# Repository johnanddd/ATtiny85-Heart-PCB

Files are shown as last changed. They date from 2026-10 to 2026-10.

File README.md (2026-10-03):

# ATtiny85 Heart PCB

A custom heart-shaped PCB built around an ATtiny85 microcontroller with 24 red LEDs, four transistor-switched lighting groups, a pushbutton for changing animation modes, and non-blocking embedded firmware.

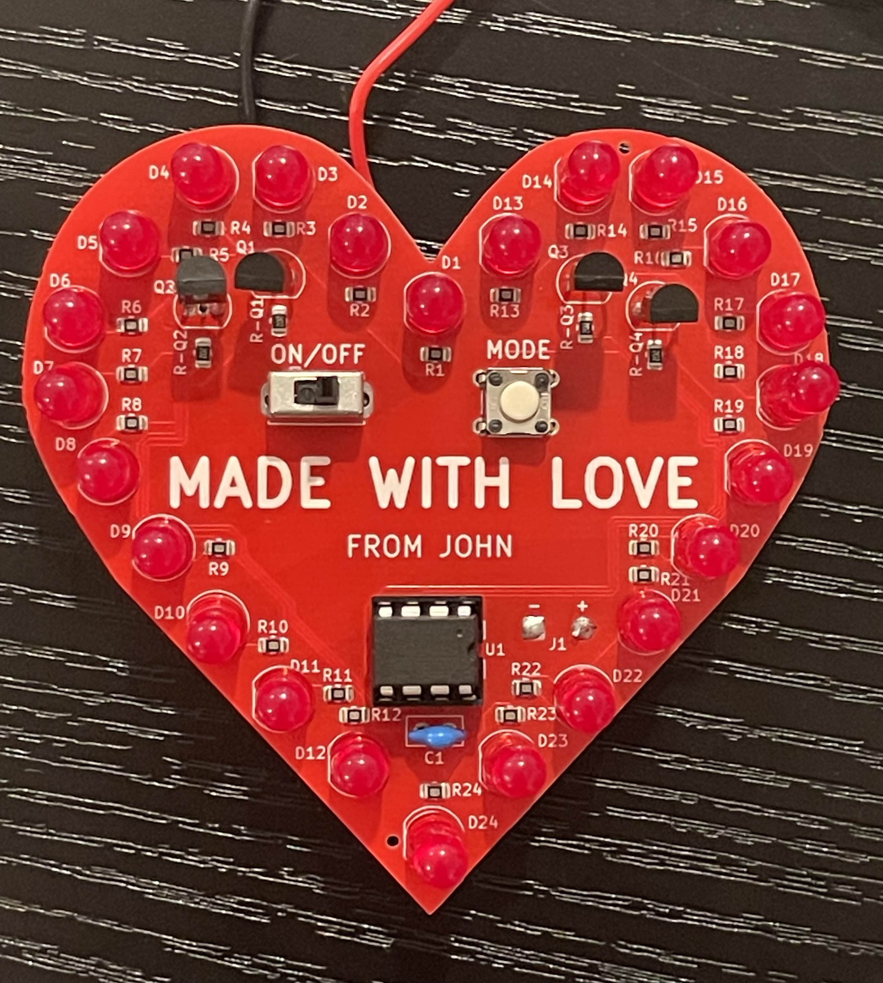
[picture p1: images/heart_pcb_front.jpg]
Finished ATtiny85 Heart PCB


## Demo

[Watch the LED animation demo on YouTube](https://youtube.com/shorts/_cduVnqTBQo)

The MODE button cycles through five lighting patterns:

1. All LEDs continuously on
2. Slow heartbeat — 500 ms on / 500 ms off
3. Fast heartbeat — 250 ms on / 250 ms off
4. Circular group sequence — Q1 → Q2 → Q4 → Q3
5. Alternating opposite groups — Q1 + Q4 ↔ Q2 + Q3

## Hardware

- ATtiny85 microcontroller
- 24 × 5 mm red LEDs
- 24 × 1 kΩ LED current-limiting resistors
- 4 × PN2222A NPN transistors
- 4 × 2 kΩ transistor base resistors
- MODE pushbutton
- ON/OFF slide switch
- 100 nF decoupling capacitor
- 3 × AA battery supply
- Custom 2-layer heart-shaped PCB

The 24 LEDs are split into four groups. Each group is switched by an NPN transistor controlled by one ATtiny85 GPIO pin.

## Schematic

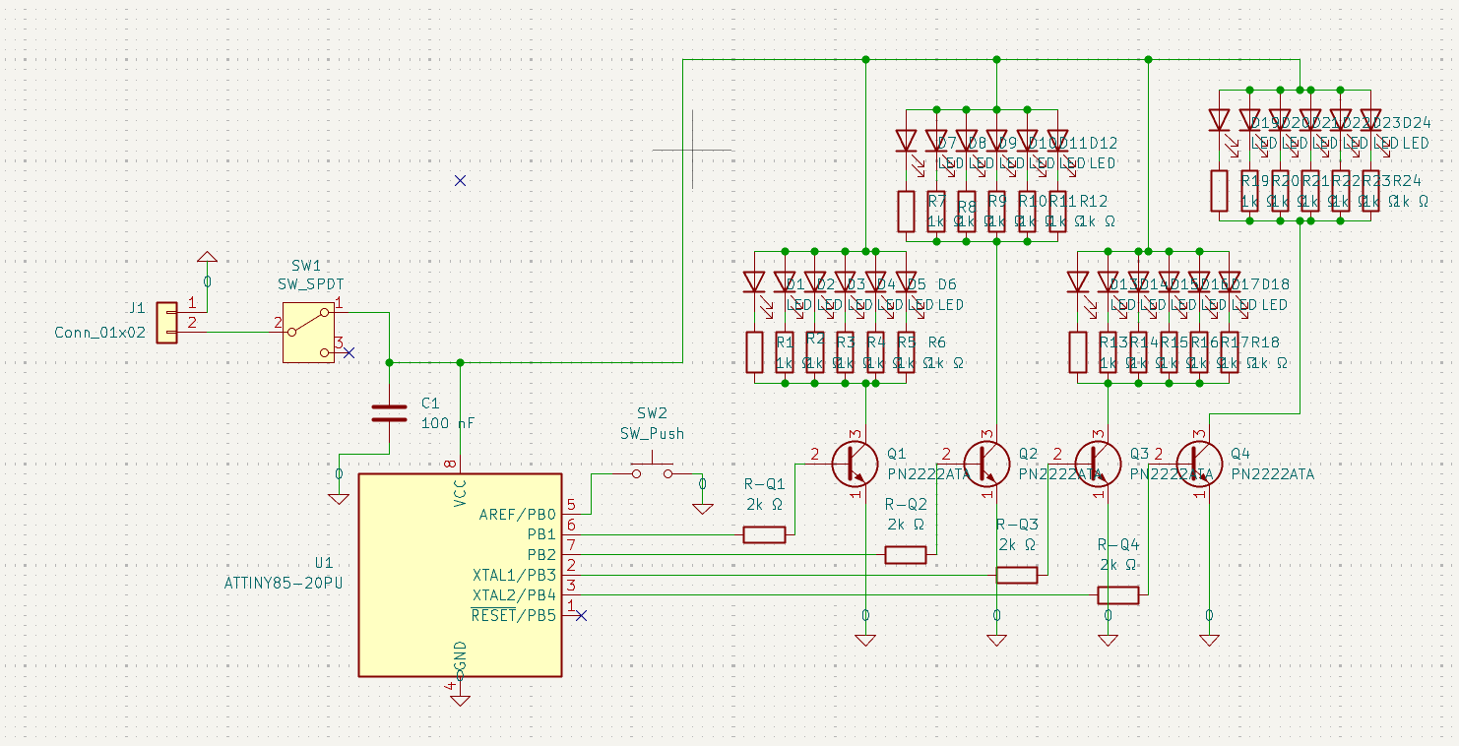
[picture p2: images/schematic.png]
Schematic


PB0 is connected to the MODE button using the ATtiny85's internal pull-up resistor. PB1–PB4 control the four transistor-switched LED groups.

## PCB Design

The board was designed in KiCad as a custom 2-layer heart-shaped PCB with a red solder mask and white silkscreen.

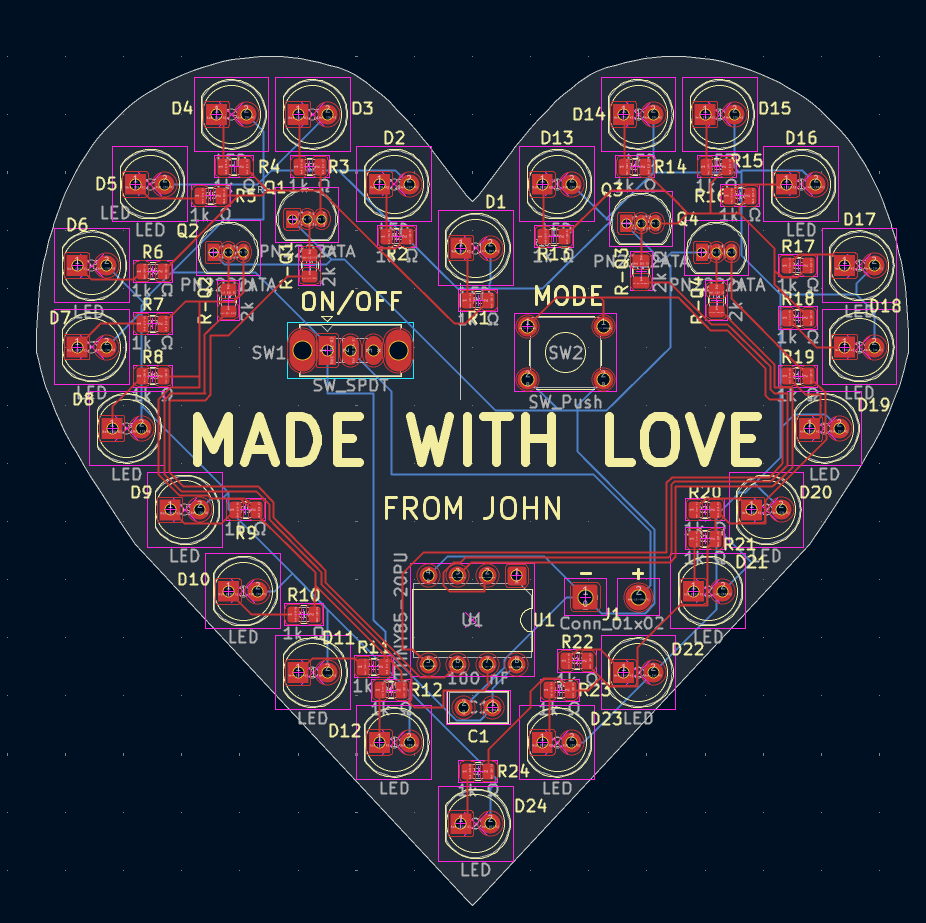
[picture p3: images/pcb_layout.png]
PCB Layout


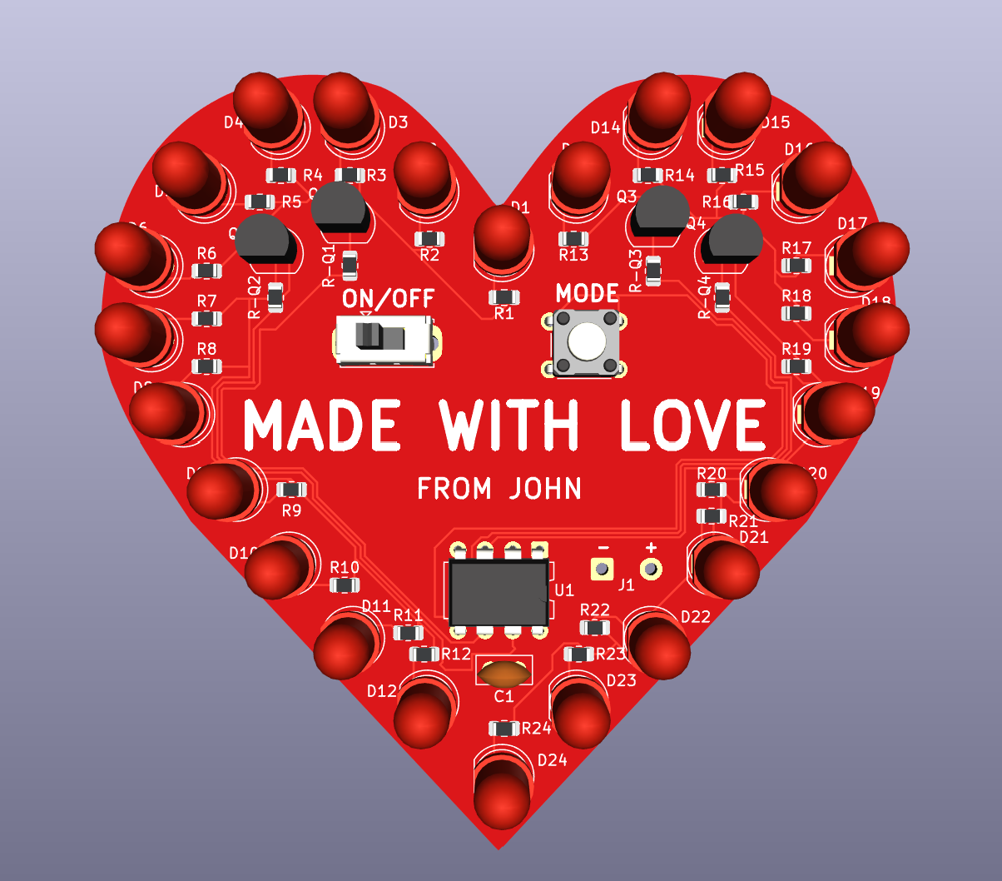
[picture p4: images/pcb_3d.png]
PCB 3D View


## Firmware

The firmware is written in Arduino C/C++ for the ATtiny85 and is available in `firmware/attiny85_heartpcb_v1.ino`.

The MODE button uses the ATtiny85's PB0 pin-change interrupt. The ISR only sets a flag, while the main loop handles debouncing and mode changes.

All animation timing is non-blocking and uses `millis()` rather than `delay()`. Each animation keeps track of its own state so the board can respond to button presses while an animation is running.

The ATtiny85 is configured to use its internal 1 MHz clock.

## Finished Board

### Front

Front of finished PCB

### Back

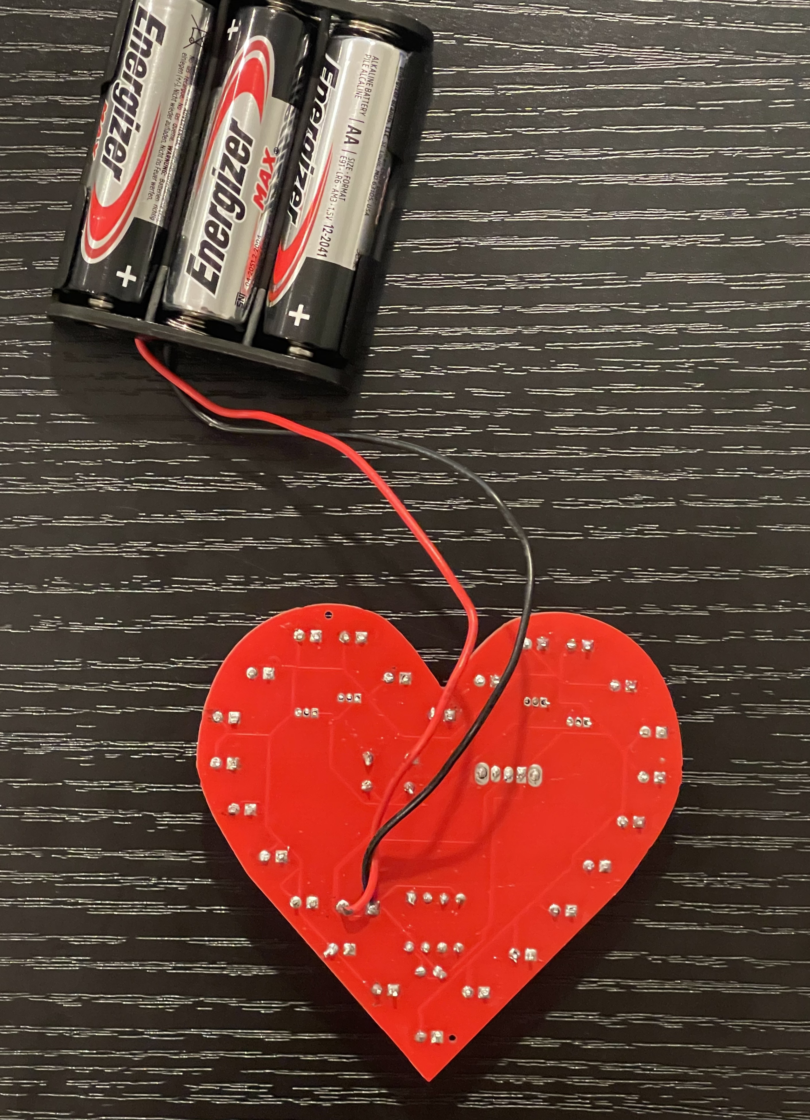
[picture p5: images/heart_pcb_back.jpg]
Back of finished PCB


## Manufacturing and Assembly

The PCB was fabricated by JLCPCB. The surface-mount resistors were populated through PCBA, while the through-hole LEDs, transistors, ATtiny85 socket, switch, pushbutton, capacitor, and battery wiring were assembled by hand.

The repository also includes the KiCad project files:

- `hardware/heart_pcb_v1.kicad_pro`
- `hardware/heart_pcb_v1.kicad_sch`
- `hardware/heart_pcb_v1.kicad_pcb`

## What I Learned

This project covered the full workflow from circuit design through a working physical board:

- Schematic capture and PCB layout in KiCad
- Component placement and routing
- Transistor switching for grouped LED loads
- PCB fabrication and PCBA workflow
- Through-hole and SMD assembly
- ATtiny85 register configuration and pin-change interrupts
- Software button debouncing
- Non-blocking timing with `millis()`
- State-machine based LED animations
- Hardware debugging and continuity testing

One of the biggest lessons from V1 was designing for assembly and reliability. The through-hole TO-92 transistors were difficult to solder and rework because of the tight lead spacing. A future V2 will likely move more of the design to surface-mount parts, including SMD transistors and LEDs, so most of the board can be assembled directly by the manufacturer.

## Repository Structure

```text
ATtiny85-Heart-PCB/
├── README.md
├── firmware/
│   └── attiny85_heartpcb_v1.ino
├── hardware/
│   ├── heart_pcb_v1.kicad_pro
│   ├── heart_pcb_v1.kicad_sch
│   ├── heart_pcb_v1.kicad_pcb
│   └── heart_pcb_v1.kicad_prl
└── images/
    ├── heart_pcb_front.jpg
    ├── heart_pcb_back.jpg
    ├── pcb_3d.png
    ├── pcb_layout.png
    └── schematic.png
```

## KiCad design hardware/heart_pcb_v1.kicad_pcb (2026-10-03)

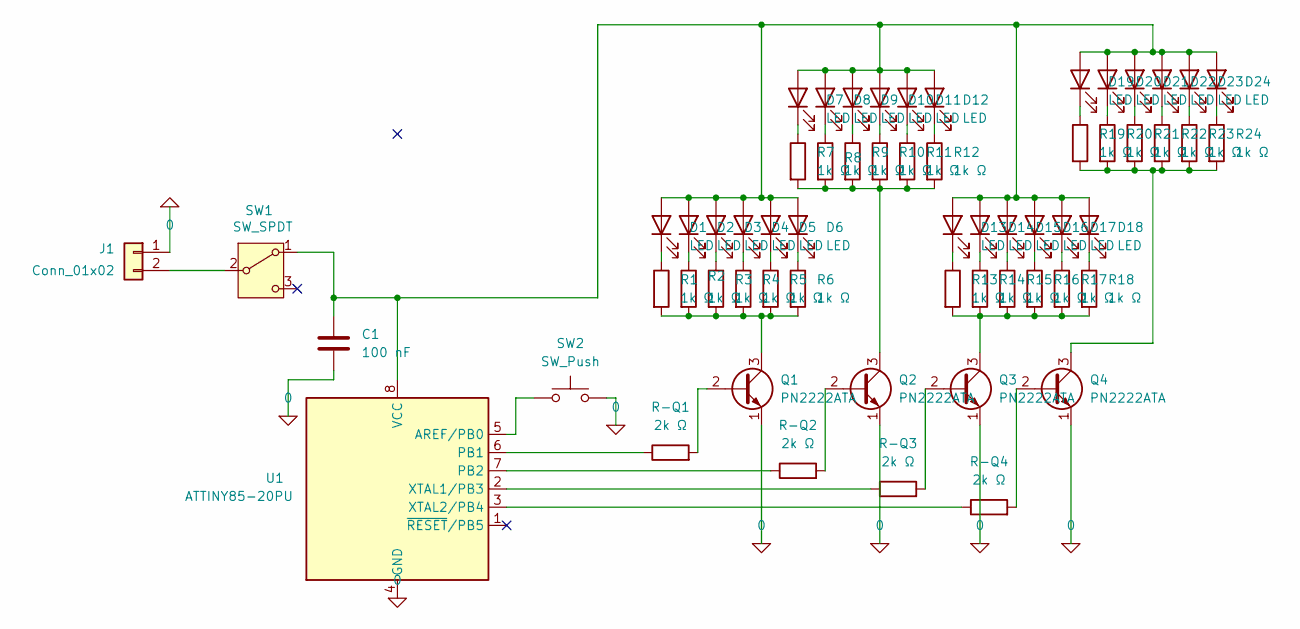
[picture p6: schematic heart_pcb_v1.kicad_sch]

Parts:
C1: 100 nF; C_Disc_D5.0mm_W2.5mm_P2.50mm
D1, D2, D3, D4, D5, D6, D7, D8, D9, D10, D11, D12, D13, D14, D15, D16, D17, D18, D19, D20, D21, D22, D23, D24: LED; LED_D5.0mm
J1: Conn_01x02; SolderWire-0.5sqmm_1x02_P4.6mm_D0.9mm_OD2.1mm
Q1, Q2, Q3, Q4: PN2222ATA; TO-92_Inline
R1, R2, R3, R4, R5, R6, R7, R8, R9, R10, R11, R12, R13, R14, R15, R16, R17, R18, R19, R20, R21, R22, R23, R24: 1k Ω; R_0805_2012Metric
R-Q1, R-Q2, R-Q3, R-Q4: 2k Ω; R_0805_2012Metric
SW1: SW_SPDT; SW_Slide_SPDT_Straight_CK_OS102011MS2Q
SW2: SW_Push; SW_TH_Tactile_Omron_B3F-100x
U1: ATTINY85-20PU; DIP-8_W7.62mm

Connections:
0: C1.2, J1.1, Q1.1 (E), Q2.1 (E), Q3.1 (E), Q4.1 (E), SW2.2, U1.4 (GND)
unnamed: C1.1, D1.2 (A), D2.2 (A), D3.2 (A), D4.2 (A), D5.2 (A), D6.2 (A), D7.2 (A), D8.2 (A), D9.2 (A), D10.2 (A), D11.2 (A), D12.2 (A), D13.2 (A), D14.2 (A), D15.2 (A), D16.2 (A), D17.2 (A), D18.2 (A), D19.2 (A), D20.2 (A), D21.2 (A), D22.2 (A), D23.2 (A), D24.2 (A), SW1.1 (A), U1.8 (VCC)
unnamed: D1.1 (K), R1.1
unnamed: D2.1 (K), R2.1
unnamed: D3.1 (K), R3.1
unnamed: D4.1 (K), R4.1
unnamed: D5.1 (K), R5.1
unnamed: D6.1 (K), R6.1
unnamed: D7.1 (K), R7.1
unnamed: D8.1 (K), R8.1
unnamed: D9.1 (K), R9.1
unnamed: D10.1 (K), R10.1
unnamed: D11.1 (K), R11.1
unnamed: D12.1 (K), R12.1
unnamed: D13.1 (K), R13.1
unnamed: D14.1 (K), R14.1
unnamed: D15.1 (K), R15.1
unnamed: D16.1 (K), R16.1
unnamed: D17.1 (K), R17.1
unnamed: D18.1 (K), R18.1
unnamed: D19.1 (K), R19.1
unnamed: D20.1 (K), R20.1
unnamed: D21.1 (K), R21.1
unnamed: D22.1 (K), R22.1
unnamed: D23.1 (K), R23.1
unnamed: D24.1 (K), R24.1
unnamed: J1.2, SW1.2 (B)
unnamed: Q1.2 (B), R-Q1.2
unnamed: Q1.3 (C), R1.2, R2.2, R3.2, R4.2, R5.2, R6.2
unnamed: Q2.2 (B), R-Q2.2
unnamed: Q2.3 (C), R7.2, R8.2, R9.2, R10.2, R11.2, R12.2
unnamed: Q3.2 (B), R-Q3.2
unnamed: Q3.3 (C), R13.2, R14.2, R15.2, R16.2, R17.2, R18.2
unnamed: Q4.2 (B), R-Q4.2
unnamed: Q4.3 (C), R19.2, R20.2, R21.2, R22.2, R23.2, R24.2
unnamed: SW2.1, U1.5 (AREF/PB0)
unnamed: R-Q1.1, U1.6 (PB1)
unnamed: R-Q2.1, U1.7 (PB2)
unnamed: R-Q3.1, U1.2 (XTAL1/PB3)
unnamed: R-Q4.1, U1.3 (XTAL2/PB4)

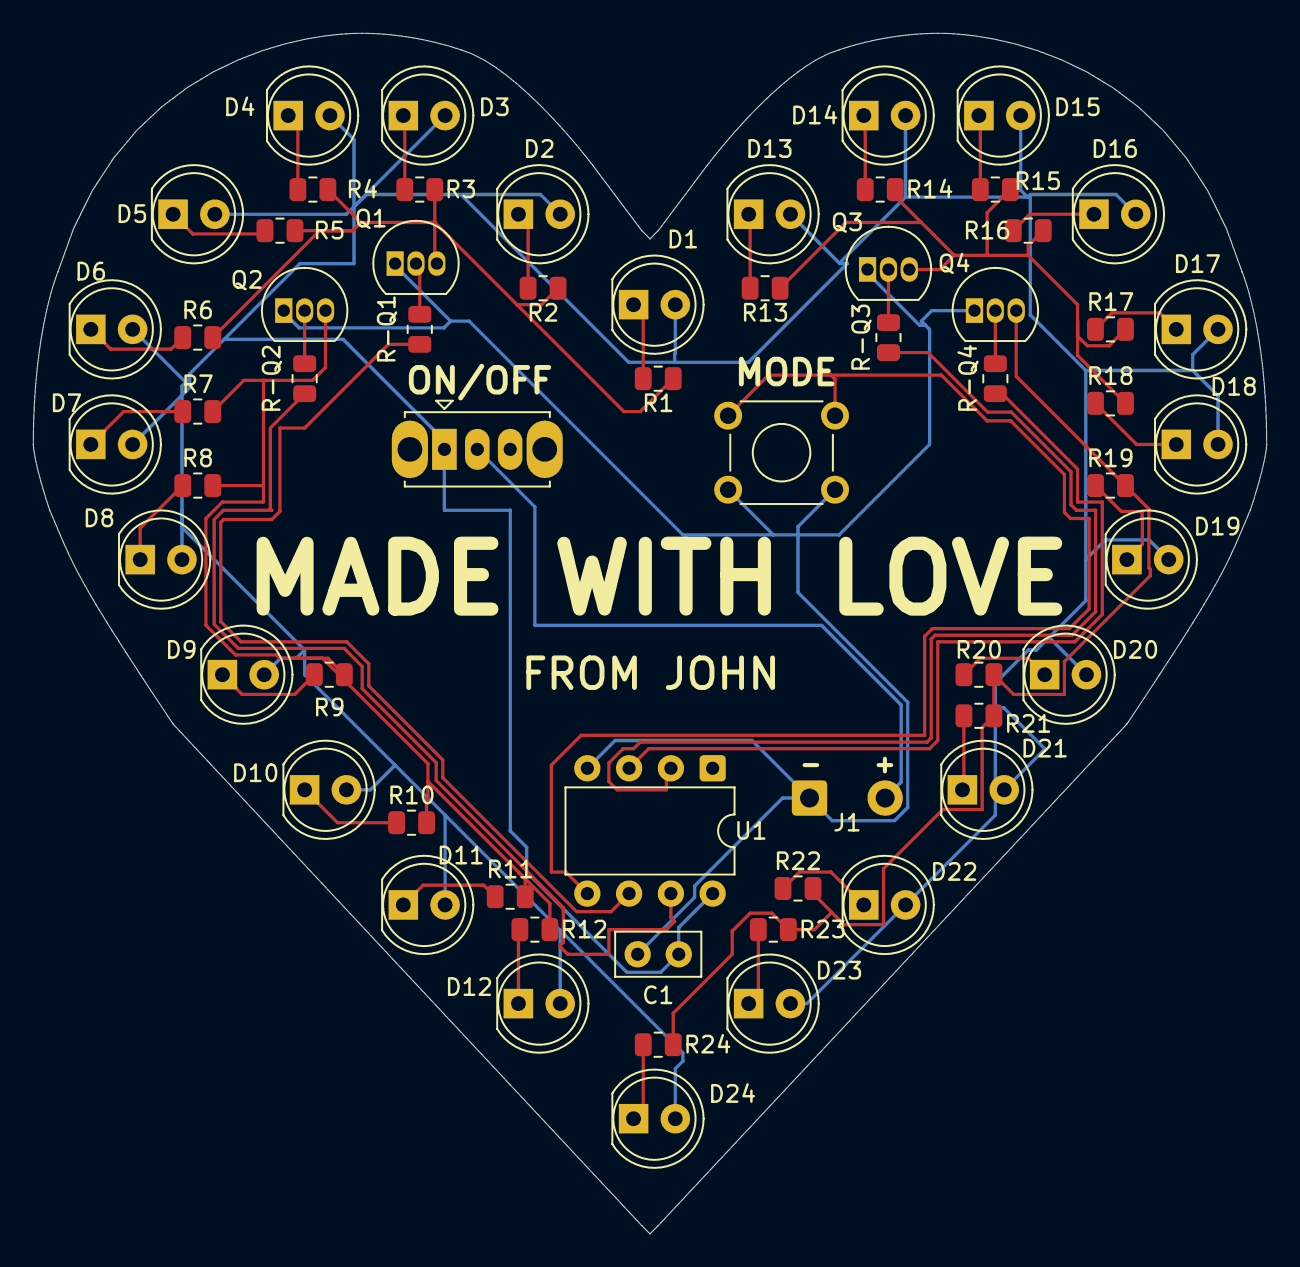
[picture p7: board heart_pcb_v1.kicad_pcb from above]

Board: 2 copper layers, 75.0 x 73.0 mm, 61 parts (0 on the bottom side), 40 nets.

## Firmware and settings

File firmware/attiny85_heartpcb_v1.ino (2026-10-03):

#include <avr/interrupt.h>

const int button_pin = 0;
unsigned long previous_time = 0;
volatile bool buttonPressed = false;

int mode = 1;
const int modes_amount = 5;

int mode2_step = 1;
int mode3_step = 1;
int mode4_step = 1;
int mode5_step = 1;

// Transistor layout:
// Pin1 - Q1, Top Left LEDs
// Pin2 - Q2, Bottom left
// Pin3 - Q3, Top right
// Pin4 - Q4, Bottom right

// Mode ideas:
// Mode 1 - default, just all lights constantly on so all 4 transistors toggled. 
// Mode 2 - beating heart, all come on for half a second then go off for half a second
// Mode 3 - faster beating heart, all come on for 1/4 a second then go off for 1/4 a second
// Mode 4 - Cycling LEDs: Q1 toggles for 1/8 a second, then Q2, then Q4, then Q3, in a circular cycle.
// Mode 5 - Opposite sides cycle: Q1 + Q4 for 1/4 a second, then Q2 + Q3 for 1/4 a second

void setup() {
  pinMode(button_pin, INPUT_PULLUP);      // PB0 normally HIGH, button pulls it to GND

  pinMode(1, OUTPUT);
  pinMode(2, OUTPUT);
  pinMode(3, OUTPUT);
  pinMode(4, OUTPUT);

  GIMSK |= (1 << PCIE);          // enable pin-change interrupts
  PCMSK |= (1 << PCINT0);        // enable interrupt specifically on PB0
  GIFR  = (1 << PCIF);           // clear any old pending interrupt flag
  sei();                         // enable interrupts globally
}

ISR(PCINT0_vect) {
  if (digitalRead(button_pin) == LOW) {
    buttonPressed = true;
  }
}

void mode1() {
    digitalWrite(1, HIGH);
    digitalWrite(2, HIGH);
    digitalWrite(3, HIGH);
    digitalWrite(4, HIGH);
}


void mode2() {
    if ((millis() - previous_time >= 500) || (previous_time == 0)) {
      previous_time = millis();
      
      if (mode2_step == 1) {
        digitalWrite(1, HIGH);
        digitalWrite(2, HIGH);
        digitalWrite(3, HIGH);
        digitalWrite(4, HIGH);
        mode2_step += 1;
      }
      else {
        digitalWrite(1, LOW);
        digitalWrite(2, LOW);
        digitalWrite(3, LOW);
        digitalWrite(4, LOW);
        mode2_step = 1;
      }    

    }  
}


void mode3() {
    if ((millis() - previous_time >= 250) || (previous_time == 0)) {
      previous_time = millis();
      
      if (mode3_step == 1) {
        digitalWrite(1, HIGH);
        digitalWrite(2, HIGH);
        digitalWrite(3, HIGH);
        digitalWrite(4, HIGH);
        mode3_step += 1;
      }
      else {
        digitalWrite(1, LOW);
        digitalWrite(2, LOW);
        digitalWrite(3, LOW);
        digitalWrite(4, LOW);
        mode3_step = 1;
      }    

    }  
}


void mode4() {
  if ((millis() - previous_time >= 125) || (previous_time == 0)) {
    previous_time = millis();
    
    // turn everything off
    digitalWrite(1, LOW);
    digitalWrite(2, LOW);
    digitalWrite(3, LOW);
    digitalWrite(4, LOW);

    if (mode4_step == 1) {
      digitalWrite(1, HIGH);
      mode4_step += 1;
    }
    else if (mode4_step == 2)
    {
      digitalWrite(2, HIGH);
      mode4_step += 1;
    }
    else if (mode4_step == 3)
    {
      digitalWrite(4, HIGH);
      mode4_step += 1;
    }
    else
    {
      digitalWrite(3, HIGH);
      mode4_step = 1;
    }

  }
}


void mode5() {
  if ((millis() - previous_time >= 250) || (previous_time == 0)) {
    previous_time = millis();

    // turn everything off
    digitalWrite(1, LOW);
    digitalWrite(2, LOW);
    digitalWrite(3, LOW);
    digitalWrite(4, LOW);

    if (mode5_step == 1) {
      digitalWrite(1, HIGH);
      digitalWrite(4, HIGH);
      mode5_step += 1;
    }
    else {
      digitalWrite(2, HIGH);
      digitalWrite(3, HIGH);
      mode5_step = 1;
    }
  }
}
unsigned long last_button_press = 0;
const unsigned long debounce_time = 25;

void loop() {
  if (buttonPressed == true) {
    buttonPressed = false;

    if (millis() - last_button_press >= debounce_time) {
      last_button_press = millis();

      if (mode < modes_amount) {
        mode += 1;
      }
      else {
        mode = 1;
      }

      previous_time = 0;

      digitalWrite(1, LOW);
      digitalWrite(2, LOW);
      digitalWrite(3, LOW);
      digitalWrite(4, LOW);

      mode2_step = 1;
      mode3_step = 1;
      mode4_step = 1;
      mode5_step = 1;
    }
  }

  if (mode == 1) {
    mode1();
  }
  
  if (mode == 2) {
    mode2();
  }

  if (mode == 3) {
    mode3();
  }

  if (mode == 4) {
    mode4();
  }

  if (mode == 5) {
    mode5();
  }
}
